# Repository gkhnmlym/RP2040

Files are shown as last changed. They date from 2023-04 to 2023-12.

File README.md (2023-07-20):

# RP2040

"RP2040 is a microcontroller chip developed by Raspberry Pi, based on the ARM Cortex-M0+ core. This chip has gained popularity due to several advantages, especially for embedded systems and microcontroller projects. Here are some of the advantages of RP2040:

-Performance: RP2040 features an ARM Cortex-M0+ core running at 133MHz, allowing it to execute complex operations quickly and deliver efficient performance in high-speed applications.

-Expandable Memory: RP2040 comes with 264 KB of internal SRAM, and it offers options for expandable memory using external devices like SPI Flash.

-Multiple I/O Options: With a large number of I/O pins, RP2040 can be used for various purposes, including digital and analog inputs/outputs, UART, I2C, SPI, and PWM. This enables easy integration with a wide range of sensors, displays, and other external devices.

-Low-Jitter Clock: RP2040 generates a low-jitter clock, which is beneficial for applications requiring precise timing. It ensures better performance in tasks involving audio, video, and other synchronization needs.

-Flexible Development Environment: Raspberry Pi provides the RP2040 SDK and Arduino Core, making it easy for developers to work on RP2040-based projects using various programming languages and tools.

-Low Power Consumption: RP2040 incorporates low-power modes and optimized operation modes, resulting in energy efficiency. This feature is advantageous for battery-powered applications, providing a longer battery life.

-Cost-Effective: RP2040 is a budget-friendly microcontroller chip, making it an ideal choice to reduce project costs and cater to a wide user base.

-Community Support: Being backed by a vast community, RP2040-based projects benefit from a platform where users can share knowledge, experiences, and receive assistance.

-All these advantages make RP2040 a popular choice for embedded systems, hobby electronics, and microcontroller-based projects."

The image below shows the PCB layout with KiCad design.


You can get help from the link for the software.

-( https://www.youtube.com/watch?v=i8MqFmR0W3E )

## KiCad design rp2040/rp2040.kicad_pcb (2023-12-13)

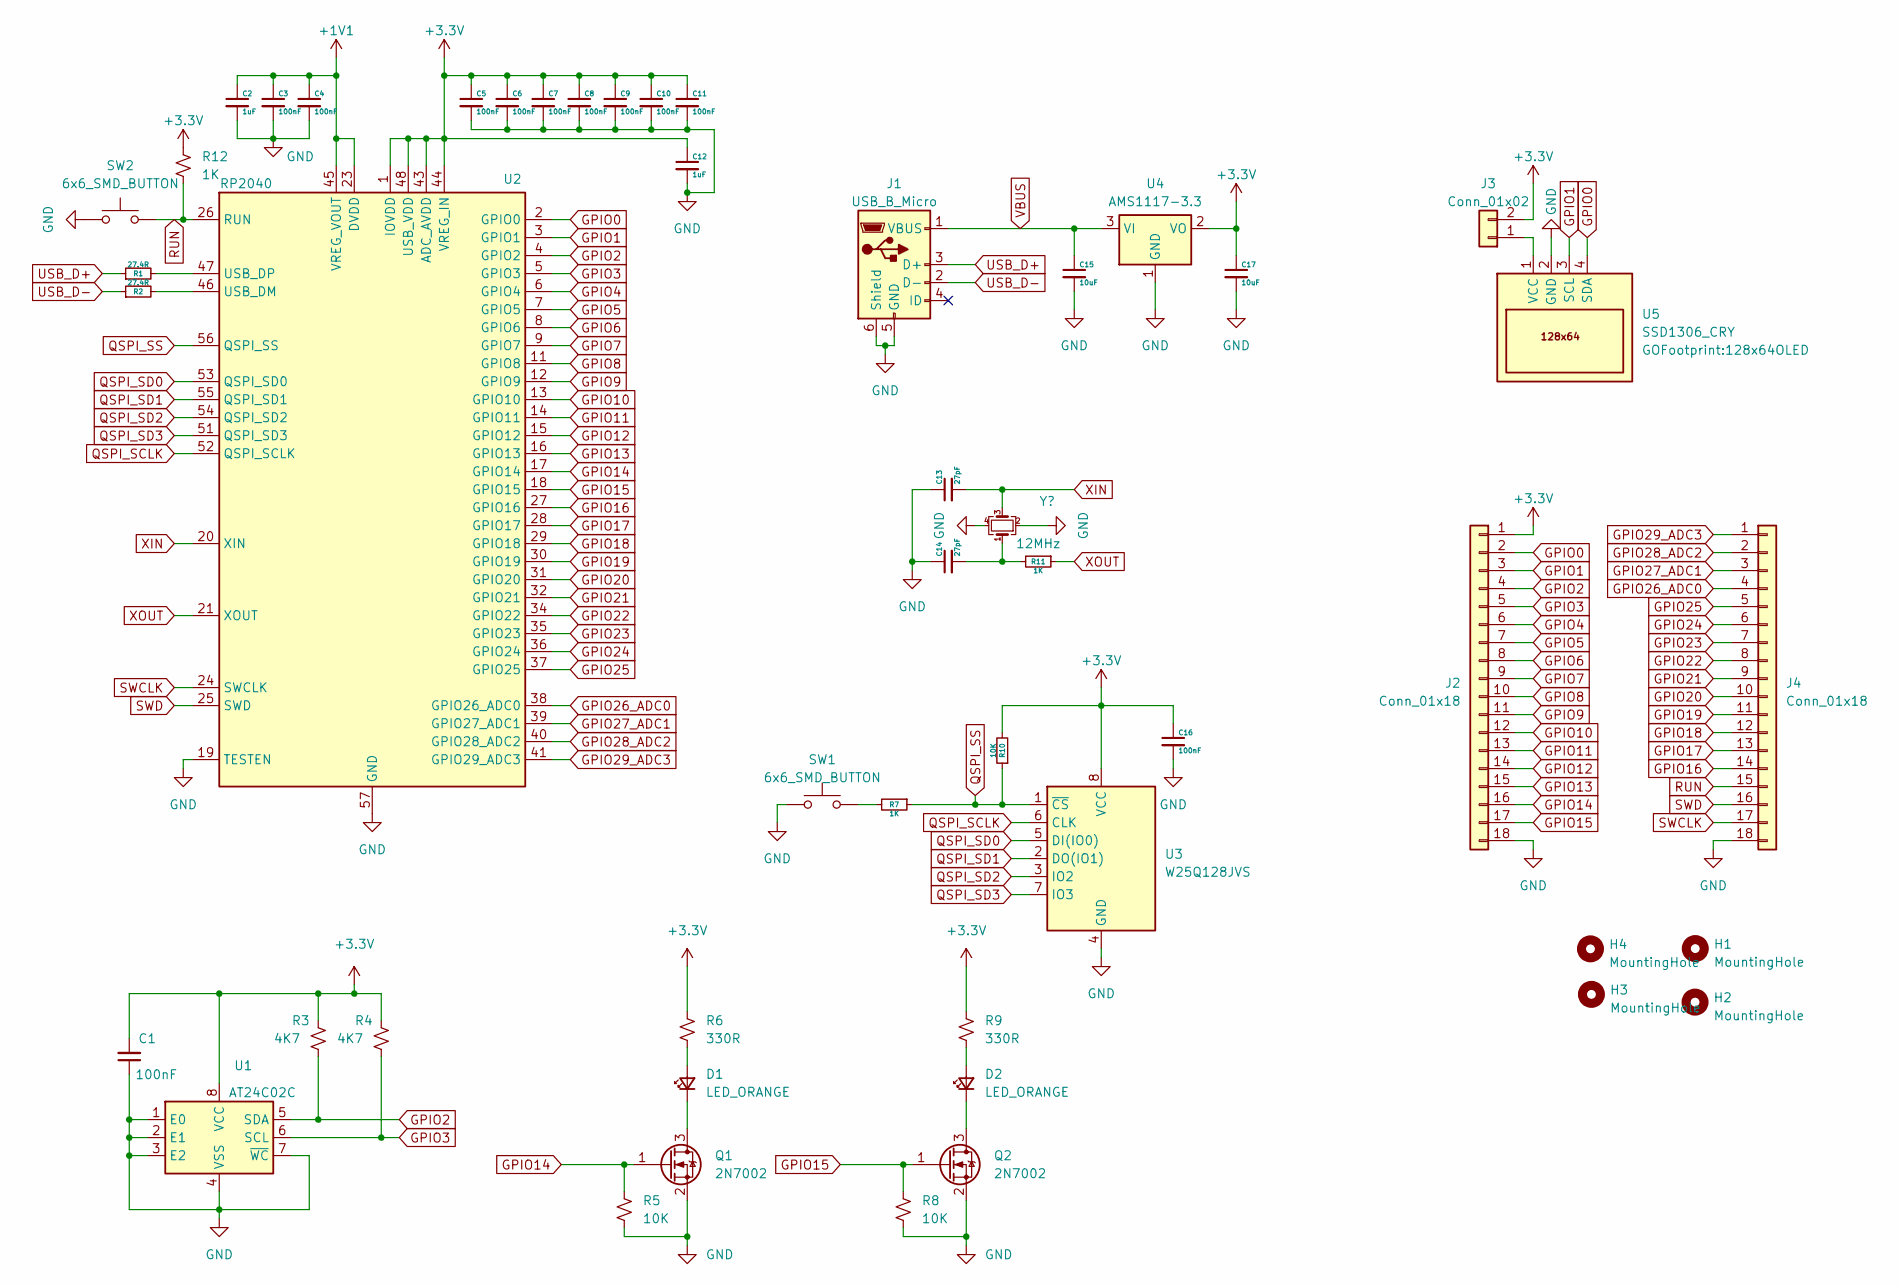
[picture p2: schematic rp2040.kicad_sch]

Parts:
C1: 100nF; C_0805_2012Metric
C2, C12: 1uF; C_0603_1608Metric
C3, C4, C5, C6, C7, C8, C9, C10, C11, C16: 100nF; C_0603_1608Metric
C13, C14: 27pF; C_0603_1608Metric
C15, C17: 10uF; C_0603_1608Metric
D1, D2: LED_ORANGE; LED_0805_2012Metric
H1, H2, H3, H4: MountingHole; MountingHole_3.2mm_M3_Pad_Via
J1: USB_B_Micro; USB_Micro-B_GCT_USB3076-30-A
J2, J4: Conn_01x18; PinHeader_1x18_P2.54mm_Vertical
J3: Conn_01x02; PinHeader_1x02_P2.54mm_Vertical
Q1, Q2: 2N7002; SOT-23
R1, R2: 27.4R; R_0603_1608Metric
R3, R4: 4K7; R_0805_2012Metric
R5, R8: 10K; R_0805_2012Metric
R6, R9: 330R; R_0805_2012Metric
R7, R11: 1K; R_0603_1608Metric
R10: 10K; R_0603_1608Metric
R12: 1K; R_0805_2012Metric
SW1, SW2: 6x6_SMD_BUTTON; SW_SPST_CK_RS282G05A3
U1: AT24C02C; SOIC-8_3.9x4.9mm_P1.27mm
U2: RP2040; QFN-56-1EP_7x7mm_P0.4mm_EP3.2x3.2mm
U3: W25Q128JVS; SOIC-8_5.23x5.23mm_P1.27mm
U4: AMS1117-3.3; SOT-223-3_TabPin2
U5: SSD1306_CRY; 128x64OLED
Y1: 12MHz; Crystal_SMD_5032-4Pin_5.0x3.2mm

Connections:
+1V1: C2.1, C3.1, C4.1, U2.23 (DVDD), U2.45 (VREG_VOUT), U2.50 (DVDD)
+3.3V: C1.2, C5.1, C6.1, C7.1, C8.1, C9.1, C10.1, C11.1, C12.1, C16.1, C17.1, J2.1, J3.2, R3.1, R4.1, R6.2, R9.2, R10.2, R12.2, U1.8 (VCC), U2.1 (IOVDD), U2.10 (IOVDD), U2.22 (IOVDD), U2.33 (IOVDD), U2.42 (IOVDD), U2.43 (ADC_AVDD), U2.44 (VREG_IN), U2.48 (USB_VDD), U2.49 (IOVDD), U3.8 (VCC), U4.2 (VO)
GND: C1.1, C2.2, C3.2, C4.2, C5.2, C6.2, C7.2, C8.2, C9.2, C10.2, C11.2, C12.2, C13.1, C14.1, C15.2, C16.2, C17.2, J1.5 (GND), J1.6 (Shield), J2.18, J4.18, Q1.2 (S), Q2.2 (S), R5.2, R8.2, SW1.1, SW2.1, U1.1 (E0), U1.2 (E1), U1.3 (E2), U1.4 (VSS), U1.7 (~WC), U2.19 (TESTEN), U2.57 (GND), U3.4 (GND), U4.1 (GND), U5.2 (GND), Y1.2, Y1.4
GPIO0: J2.2, U2.2 (GPIO0), U5.4 (SDA)
GPIO1: J2.3, U2.3 (GPIO1), U5.3 (SCL)
GPIO2: J2.4, R3.2, U1.5 (SDA), U2.4 (GPIO2)
GPIO3: J2.5, R4.2, U1.6 (SCL), U2.5 (GPIO3)
GPIO4: J2.6, U2.6 (GPIO4)
GPIO5: J2.7, U2.7 (GPIO5)
GPIO6: J2.8, U2.8 (GPIO6)
GPIO7: J2.9, U2.9 (GPIO7)
GPIO8: J2.10, U2.11 (GPIO8)
GPIO9: J2.11, U2.12 (GPIO9)
GPIO10: J2.12, U2.13 (GPIO10)
GPIO11: J2.13, U2.14 (GPIO11)
GPIO12: J2.14, U2.15 (GPIO12)
GPIO13: J2.15, U2.16 (GPIO13)
GPIO14: J2.16, Q1.1 (G), R5.1, U2.17 (GPIO14)
GPIO15: J2.17, Q2.1 (G), R8.1, U2.18 (GPIO15)
GPIO16: J4.14, U2.27 (GPIO16)
GPIO17: J4.13, U2.28 (GPIO17)
GPIO18: J4.12, U2.29 (GPIO18)
GPIO19: J4.11, U2.30 (GPIO19)
GPIO20: J4.10, U2.31 (GPIO20)
GPIO21: J4.9, U2.32 (GPIO21)
GPIO22: J4.8, U2.34 (GPIO22)
GPIO23: J4.7, U2.35 (GPIO23)
GPIO24: J4.6, U2.36 (GPIO24)
GPIO25: J4.5, U2.37 (GPIO25)
GPIO26_ADC0: J4.4, U2.38 (GPIO26_ADC0)
GPIO27_ADC1: J4.3, U2.39 (GPIO27_ADC1)
GPIO28_ADC2: J4.2, U2.40 (GPIO28_ADC2)
GPIO29_ADC3: J4.1, U2.41 (GPIO29_ADC3)
unnamed: C14.2, R11.2, Y1.1
unnamed: D1.2 (A), R6.1
unnamed: D1.1 (K), Q1.3 (D)
unnamed: D2.2 (A), R9.1
unnamed: D2.1 (K), Q2.3 (D)
unnamed: J3.1, U5.1 (VCC)
unnamed: R7.2, SW1.2
unnamed: R2.2, U2.46 (USB_DM)
unnamed: R1.2, U2.47 (USB_DP)
QSPI_SCLK: U2.52 (QSPI_SCLK), U3.6 (CLK)
QSPI_SD0: U2.53 (QSPI_SD0), U3.5 (DI(IO0))
QSPI_SD1: U2.55 (QSPI_SD1), U3.2 (DO(IO1))
QSPI_SD2: U2.54 (QSPI_SD2), U3.3 (IO2)
QSPI_SD3: U2.51 (QSPI_SD3), U3.7 (IO3)
QSPI_SS: R7.1, R10.1, U2.56 (QSPI_SS), U3.1 (~CS)
RUN: J4.15, R12.1, SW2.2, U2.26 (RUN)
SWCLK: J4.17, U2.24 (SWCLK)
SWD: J4.16, U2.25 (SWD)
USB_D+: J1.3 (D+), R1.1
USB_D-: J1.2 (D-), R2.1
VBUS: C15.1, J1.1 (VBUS), U4.3 (VI)
XIN: C13.2, U2.20 (XIN), Y1.3
XOUT: R11.1, U2.21 (XOUT)

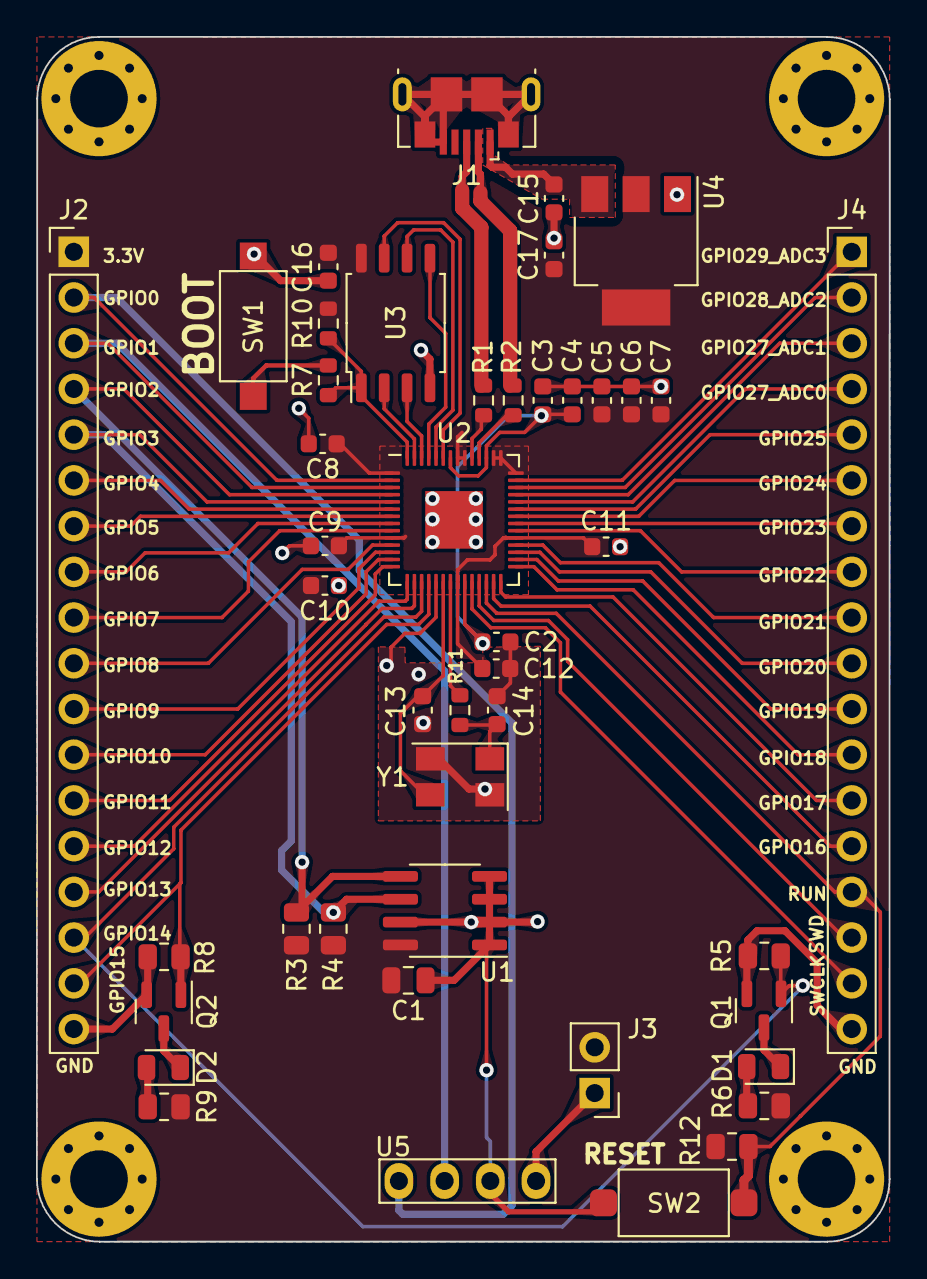
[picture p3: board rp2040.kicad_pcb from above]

Board: 2 copper layers, 47.4 x 66.9 mm, 49 parts (0 on the bottom side), 56 nets.

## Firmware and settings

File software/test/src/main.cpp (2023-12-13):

#include <Arduino.h>

const int ledPin1 = 14; // the pin that the LED is attached to
const int ledPin2 = 15; // the pin that the LED is attached to

// put function declarations here:

void setup()
{
  Serial.begin(9600);

  pinMode(ledPin1, OUTPUT);
  pinMode(ledPin2, OUTPUT);

  digitalWrite(ledPin1, LOW);
  digitalWrite(ledPin2, LOW);
}

void loop()
{

  digitalWrite(ledPin1, HIGH);
  digitalWrite(ledPin2, LOW);
  delay(100);
  digitalWrite(ledPin1, LOW);
  digitalWrite(ledPin2, HIGH);
  delay(100);
}

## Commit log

2023-06-22 edit pcb
    [rp2040.kicad_pcb, rp2040.kicad_sch]
2023-06-22 silkscreen fixed
    [rp2040.kicad_pcb]
2023-12-13 add Reset buton
    [rp2040-B_Cu.gbr, rp2040-B_Mask.gbr, rp2040-B_Paste.gbr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]
2023-12-13 add teardrop
    [rp2040-B_Cu.gbr, rp2040-B_Mask.gbr, rp2040-B_Paste.gbr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]
